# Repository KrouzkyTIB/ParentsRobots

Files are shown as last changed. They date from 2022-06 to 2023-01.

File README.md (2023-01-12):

# ParentsRobots
Repozitář s kódem a hardwarovými schématy pro kroužek bastelní s rodiči.

##### Jak zvolit jméno WiFi sítě robota?
 Na robotovi je 3-bitový mikro přepínač, kde pomocí navolením 0 a 1 zvolíme jméno WiFi sítě. Volíme v binární soustavě, takže je možné navolit až 8 jmen.
 
 ##### Jak se připojit k robotovi?
 Robot vytvoří svou vlastní wifi síť, ke které se můžete připojit pomocí Vašeho telefonu. Uživatelé s telefony s operačním systémem Android 10 a výš mohou
 mít problém s tím, že telefon hlásí, že v síti nedetekuje připojení k internetu. Zde pomáhá nastavit telefon pro tuto síť na statickou ip adresu.
 Ip adresa: 192.168.1.50
 Brána/Gateway: 192.168.1.1
 DNS 1: 0.0.0.0
 DNS 2: 0.0.0.0
 
 ##### Jak ovládat robota?
 Otevřete si prohlížeč na Vašem telefonu a do url boxíku napište IP adresu robota 192.168.1.10. Poté se Vám v telefonu objeví stránka na ovládání robota. 
 Na stránce naleznete joystick pro jízdu a tlačítko pro zapnutí světel.

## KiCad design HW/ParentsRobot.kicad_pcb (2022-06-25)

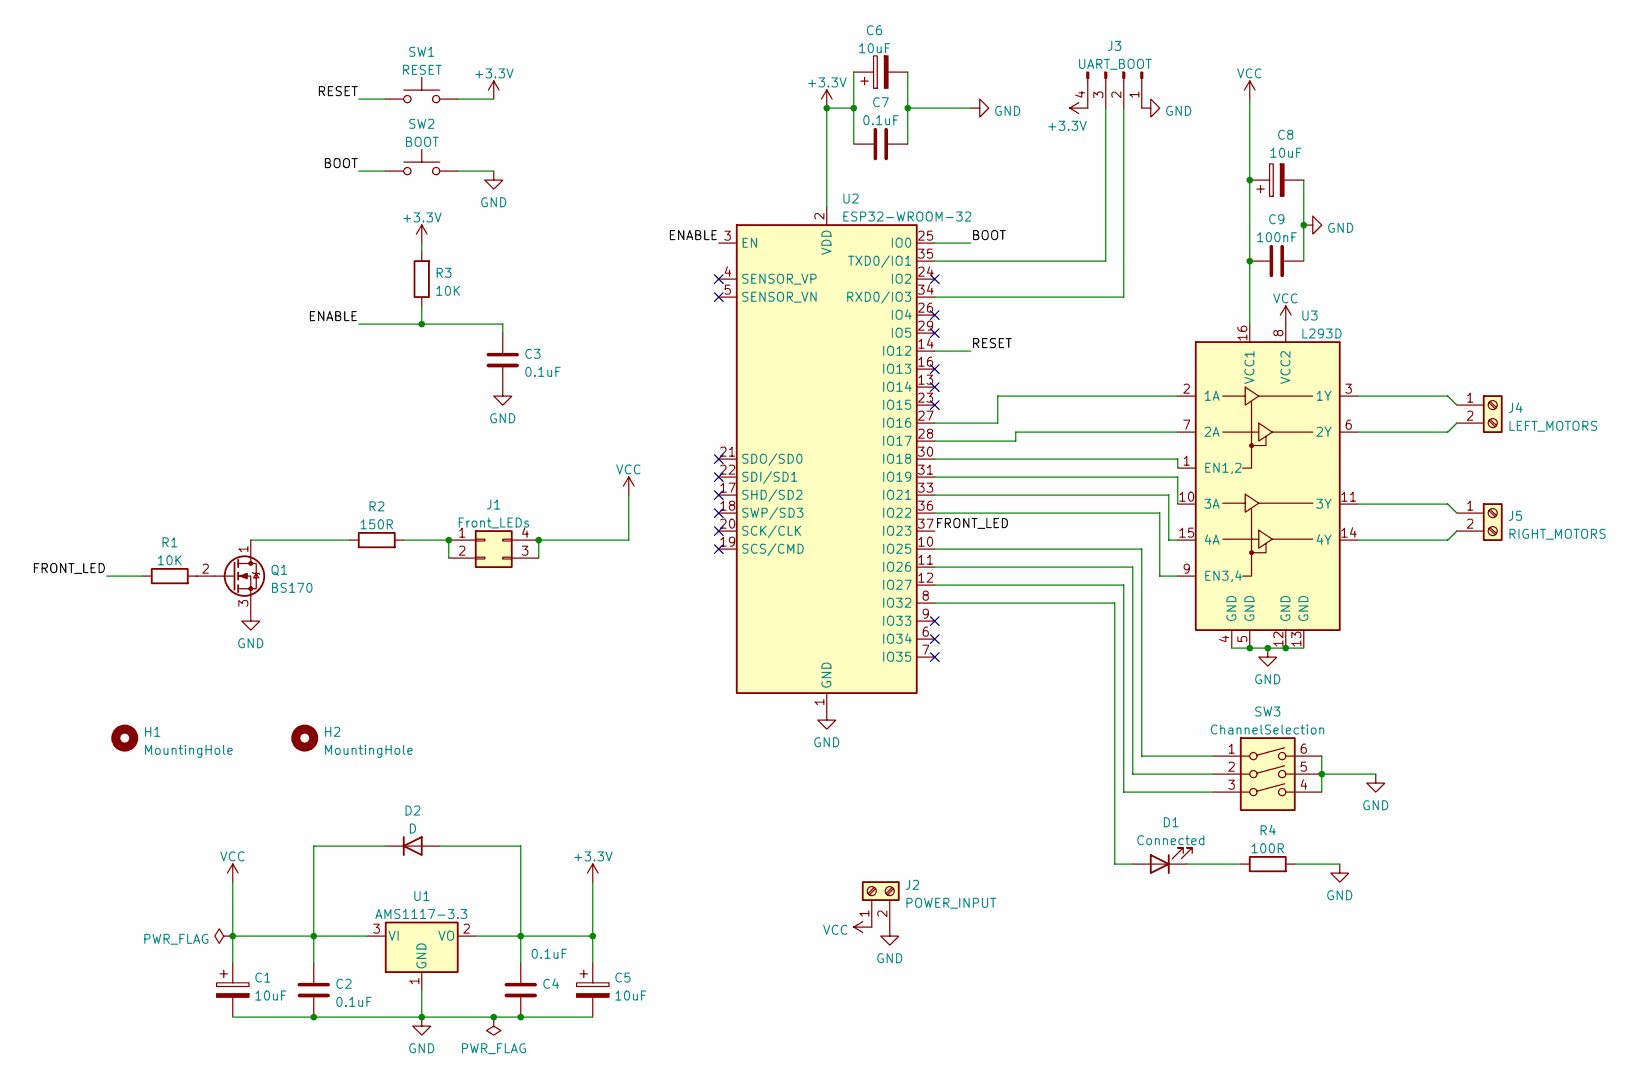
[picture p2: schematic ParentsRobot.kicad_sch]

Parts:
C1, C5, C6, C8: 10uF; CP_Radial_D4.0mm_P1.50mm
C2, C3, C4, C7: 0.1uF; C_Disc_D5.0mm_W2.5mm_P5.00mm
C9: 100nF; C_Disc_D5.0mm_W2.5mm_P5.00mm
D1: Connected; LED_D3.0mm_Clear
D2: D; D_DO-41_SOD81_P7.62mm_Horizontal
H1, H2: MountingHole; MountingHole_3.2mm_M3
J1: Front_LEDs; PinHeader_2x02_P2.54mm_Vertical
J2: POWER_INPUT; TerminalBlock_Altech_AK300-2_P5.00mm
J3: UART_BOOT; PinHeader_1x04_P2.54mm_Vertical
J4: LEFT_MOTORS; TerminalBlock_Altech_AK300-2_P5.00mm
J5: RIGHT_MOTORS; TerminalBlock_Altech_AK300-2_P5.00mm
Q1: BS170; TO-92_Inline
R1, R3: 10K; R_Axial_DIN0207_L6.3mm_D2.5mm_P7.62mm_Horizontal
R2: 150R; R_Axial_DIN0207_L6.3mm_D2.5mm_P7.62mm_Horizontal
R4: 100R; R_Axial_DIN0207_L6.3mm_D2.5mm_P7.62mm_Horizontal
SW1: RESET; SW_PUSH_6mm
SW2: BOOT; SW_PUSH_6mm
SW3: ChannelSelection; SW_DIP_SPSTx03_Slide_9.78x9.8mm_W7.62mm_P2.54mm
U1: AMS1117-3.3; SOT-223-3_TabPin2
U2: ESP32-WROOM-32
U3: L293D; DIP-16_W7.62mm

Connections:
+3V3: C4.1, C5.1, C6.1, C7.1, D2.2 (A), J3.4, R3.2, SW1.2, U1.2 (VO), U2.2 (VDD)
/BOOT: SW2.1, U2.25 (IO0)
/ENABLE: C3.1, R3.1, U2.3 (EN)
/FRONT_LED: R1.1, U2.37 (IO23)
/RESET: SW1.1, U2.14 (IO12)
GND: C1.2, C2.2, C3.2, C4.2, C5.2, C6.2, C7.2, C8.2, C9.2, J2.2, J3.1, Q1.3 (S), R4.2, SW2.2, SW3.4, SW3.5, SW3.6, U1.1 (GND), U2.1 (GND), U2.15 (GND), U2.38 (GND), U2.39 (GND), U3.4 (GND), U3.5 (GND), U3.12 (GND), U3.13 (GND)
unnamed: D1.1 (K), R4.1
unnamed: D1.2 (A), U2.8 (IO32)
unnamed: J3.2, U2.34 (RXD0/IO3)
unnamed: J3.3, U2.35 (TXD0/IO1)
unnamed: J4.1, U3.3 (1Y)
unnamed: J4.2, U3.6 (2Y)
unnamed: J5.1, U3.11 (3Y)
unnamed: J5.2, U3.14 (4Y)
unnamed: Q1.1 (D), R2.1
unnamed: Q1.2 (G), R1.2
unnamed: J1.1, J1.2, R2.2
unnamed: SW3.1, U2.10 (IO25)
unnamed: SW3.2, U2.11 (IO26)
unnamed: SW3.3, U2.12 (IO27)
unnamed: U2.27 (IO16), U3.2 (1A)
unnamed: U2.28 (IO17), U3.7 (2A)
unnamed: U2.30 (IO18), U3.1 (EN1,2)
unnamed: U2.31 (IO19), U3.10 (3A)
unnamed: U2.33 (IO21), U3.15 (4A)
unnamed: U2.36 (IO22), U3.9 (EN3,4)
VCC: C1.1, C2.1, C8.1, C9.1, D2.1 (K), J1.3, J1.4, J2.1, U1.3 (VI), U3.8 (VCC2), U3.16 (VCC1)

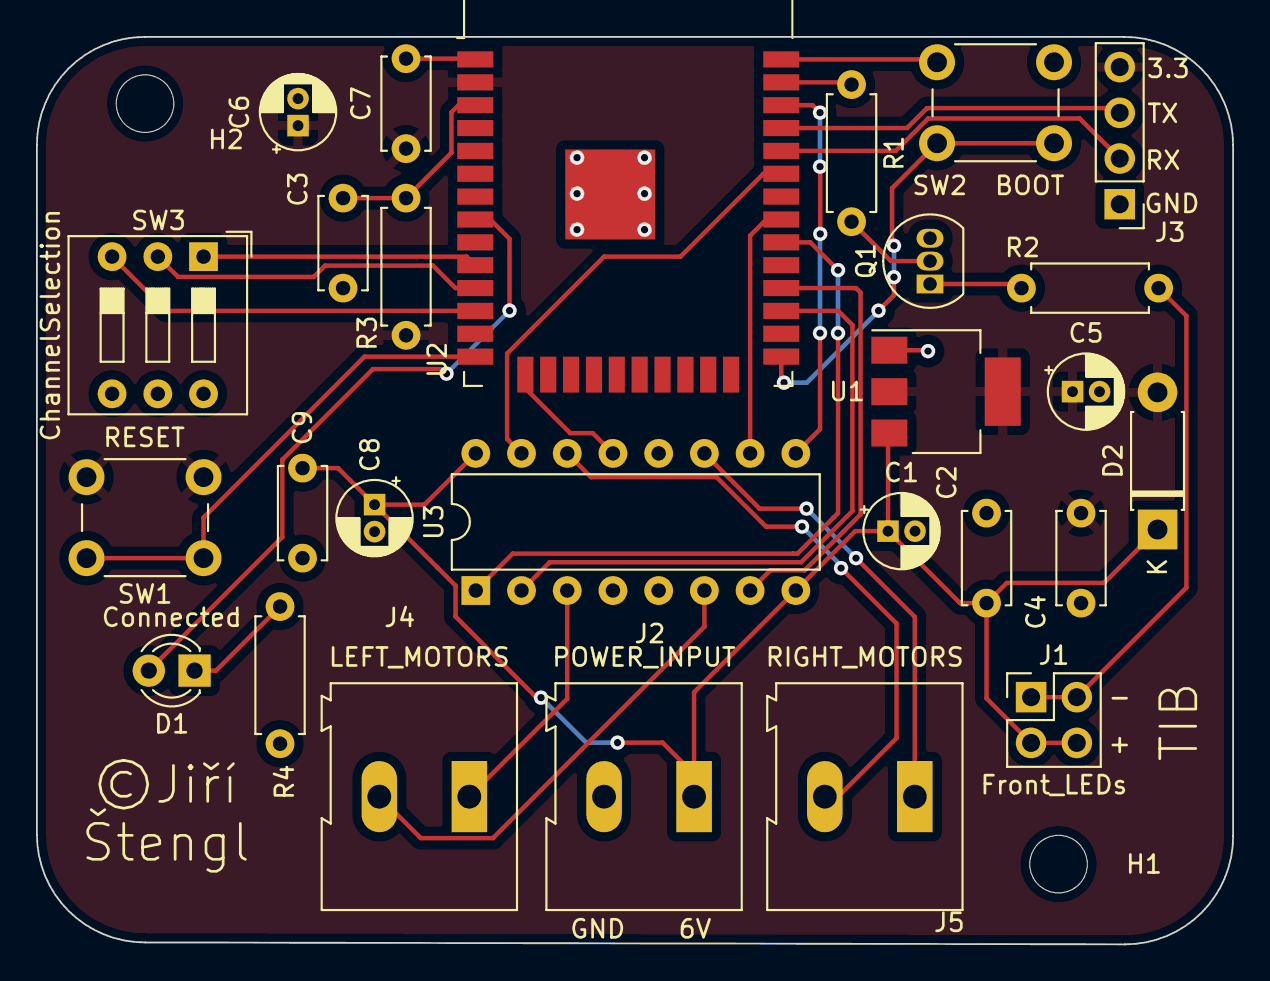
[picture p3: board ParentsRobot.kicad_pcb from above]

Board: 2 copper layers, 66.5 x 50.4 mm, 29 parts (0 on the bottom side), 27 nets.

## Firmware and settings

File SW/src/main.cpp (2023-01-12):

#include <Arduino.h>
#include <soc/rtc_cntl_reg.h>
#include "Drivers/Motor.h"
#include "PinDefinitions.h"
#include "Server/ServerHandler.h"
#include "Data/FrontEndData.h"

#define READY_BLINKING 5
Motor rightMotor(RIGHT_FORWARDS_PIN, RIGHT_BACKWARDS_PIN, RIGHT_SPEED_PIN);
Motor leftMotor(LEFT_FORWARDS_PIN, LEFT_BACKWARDS_PIN, LEFT_SPEED_PIN);
ServerHandler serverHandler;

uint8_t readWifiChannelSettings();

void setup() {

}

void loop() {
// write your code here

}


uint8_t readWifiChannelSettings() {
    pinMode(WIFI_CHANNEL_SELECTOR1, INPUT_PULLUP);
    pinMode(WIFI_CHANNEL_SELECTOR2, INPUT_PULLUP);
    pinMode(WIFI_CHANNEL_SELECTOR3, INPUT_PULLUP);
    return digitalRead(WIFI_CHANNEL_SELECTOR3) * 4 +
           digitalRead(WIFI_CHANNEL_SELECTOR2) * 2 +
           digitalRead(WIFI_CHANNEL_SELECTOR1);
}

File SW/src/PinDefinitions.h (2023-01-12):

//
// Created by jiri on 30.7.22.
//

#ifndef SW_PINS_H
#define SW_PINS_H
#define LEFT_FORWARDS_PIN 16
#define LEFT_BACKWARDS_PIN 17
#define LEFT_SPEED_PIN 18
#define RIGHT_FORWARDS_PIN 19
#define RIGHT_BACKWARDS_PIN 21
#define RIGHT_SPEED_PIN 22
#define FRONT_LED 23
#define WIFI_CHANNEL_SELECTOR1 25
#define WIFI_CHANNEL_SELECTOR2 26
#define WIFI_CHANNEL_SELECTOR3 27
#define READY_LED 32


#endif //SW_PINS_H

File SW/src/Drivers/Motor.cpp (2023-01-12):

//
// Created by jiri on 30.7.22.
//

#include "Motor.h"
#include "Arduino.h"
#define PWM_FREQUENCY 5000
#define PWM_RESOLUTION 10
#define MAX_SPEED 100
#define MAX_PWM 1024
#define MIN_SPEED 0

uint8_t Motor::channelCounter = 8;
Motor::Motor(const uint8_t forwardsPin,
             const uint8_t backwardsPin,
             const uint8_t speedPin) :
        forwardsPin(forwardsPin),
        backwardsPin(backwardsPin),
        speedPin(speedPin),
        pwmChannel(Motor::channelCounter--) {
    speed = 0;
}

void Motor::init() const {
    pinMode(forwardsPin, OUTPUT);
    pinMode(backwardsPin, OUTPUT);
    digitalWrite(forwardsPin, LOW);
    digitalWrite(backwardsPin, LOW);
    ledcSetup(pwmChannel, PWM_FREQUENCY, PWM_RESOLUTION);
    ledcAttachPin(speedPin, pwmChannel);
    ledcWrite(pwmChannel, 0);
}

void Motor::setSpeed(int8_t newSpeed) {
    if (abs(newSpeed) > MAX_SPEED) {
        return;
    }
    this->speed = newSpeed;
    if (speed == 0) {
        digitalWrite(forwardsPin, LOW);
        digitalWrite(backwardsPin, LOW);
    } else if (speed > 0) {
        digitalWrite(forwardsPin, HIGH);
        digitalWrite(backwardsPin, LOW);
    } else {
        digitalWrite(forwardsPin, LOW);
        digitalWrite(backwardsPin, HIGH);
    }
    uint32_t newPwmValue = map(abs(speed), MIN_SPEED, MAX_SPEED, 0, MAX_PWM);
    ledcWrite(pwmChannel, newPwmValue);
}

int8_t Motor::getSpeed() {
    return this->speed;
}

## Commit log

2022-06-25 Done schematic
    [ParentsRobot.kicad_pcb, ParentsRobot.kicad_sch]
2022-06-25 Done schematic. Repaired wrong used buttons and connector for front leds + assigned footprints
    [ParentsRobot.kicad_sch]
2022-06-25 Almost done PCB. Drill holes needs to be added
    [ParentsRobot.kicad_pcb, ParentsRobot.kicad_sch]
2022-06-25 Hardware done
    [ParentsRobot.kicad_pcb, ParentsRobot.kicad_sch]
2022-06-25 Added output directory for gerbers to gitingore
2022-06-25 Final version to manufacturer
    [ParentsRobot.kicad_pcb]
2022-07-31 created driver for motors
2022-08-05 Prepared button for turn on/off lights
2022-08-05 styled button for turning on/off lights
2022-09-11 fixed server but problem with page size
    [ServerHandler.cpp, main.cpp]
2022-09-11 fixed front end to send data
    [ServerHandler.cpp, main.cpp]
2022-09-12 added wifi led signal, when setup ready
2023-01-12 Added front LED controller

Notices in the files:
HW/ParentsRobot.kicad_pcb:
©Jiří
